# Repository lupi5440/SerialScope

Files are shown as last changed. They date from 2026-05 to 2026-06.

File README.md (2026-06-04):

# 🔬 SerialScope — Sistema de Análisis de Protocolos




**SerialScope** es un ecosistema de hardware y software diseñado para la visualización, análisis y emulación de protocolos de comunicación serial (**UART, I²C y SPI**). Esta introduce capacidades de **Maestro Activo**, permitiendo interactuar con sensores reales (como el MAX6675) y emular dispositivos complejos directamente desde una interfaz web .

---

## 🏗️ Arquitectura del Sistema (V3)

El sistema utiliza una arquitectura híbrida para garantizar que la visualización no afecte el rendimiento del bus físico.

```mermaid
graph TD
    subgraph Dashboard
        WEB[Interfaz Web - Vite/React]
    end

    subgraph Hardware_Cores
        VIS[ESP32 Visualizador]
        MST[ESP32 Maestro de Pruebas]
        SLV[ESP32 Esclavo de Pruebas]
    end

    WEB -- "WiFi (WebSockets)" --> VIS
    WEB -- "Bluetooth (BLE)" --> MST
    WEB -- "Bluetooth (BLE)" --> SLV

    MST -- "Bus Físico (I2C/SPI/UART)" --> VIS
    VIS -- "MISO/SDA/RX" --> WEB
    MST -- "UART" --> SLV
```

### 🛰️ Componentes Hardware
| Componente | Conectividad | Propósito |
|---|---|---|
| **Visualizador (Sniffer/Master)** | **WiFi** | Analizador lógico pasivo o **Maestro SPI/I2C** directo para leer sensores. |
| **Maestro (Emulador)** | **BLE** | Genera tráfico controlado, emula sensores (BMP180/TMP102) y controla periféricos (TFT). |
| **Esclavo (Receptor)** | **BLE** | Extremo final de la ráfaga UART para pruebas de integridad y bidireccionalidad. |

---

## 🚀 Capacidades 

### ⚡ Protocolo SPI (Serial Peripheral Interface)
- **Sniffing Pasivo:** Monitoreo en tiempo real de ráfagas MOSI/MISO sincronizadas con el reloj (SCK).
- **Maestro Activo:** Capacidad de generar el reloj (SCK) y CS para leer sensores (ej. MAX6675) y controlar periféricos (TFT).
- **Emulación de Sensor:** El visualizador puede actuar como Esclavo para responder a otros maestros con datos HEX personalizados.

### 🧩 Protocolo I²C (Inter-Integrated Circuit)
- **Auto-Sniffing:** Captura automática de direcciones y registros mediante interrupciones de hardware.
- **Maestro Activo:** Capacidad de lectura y escritura directa sobre dispositivos esclavos desde la interfaz web.
- **Emulación de Sensor:** Simulación de una memoria de registros (256 bytes) para pruebas de integración.

### 📡 Protocolo UART (Comunicación Serial)
- **Sniffing Pasivo:** Intercepción de mensajes entre dos dispositivos (Proxy transparente).
- **Maestro Activo:** Generación de mensajes seriales con baudrates configurables (9600 a 115200).
- **Emulación:** Respuesta automática controlada para validación de enlaces bidireccionales.

---

## 🛠️ Instalación y Uso

### Interfaz Web
La interfaz utiliza **Vite** para una experiencia rápida y un diseño basado en **Glassmorphism**.
```bash
cd WebInterface
npm install
npm run dev
```
Accede a `http://localhost:5173` para entrar al panel de control.

### Firmware (ESP32)
Es **CRÍTICO** utilizar el **ESP32 Arduino Core 3.0.0+** debido al uso de las APIs de PWM (`ledcAttach`). Puedes encontrar más información sobre este cambio [aquí](https://docs.espressif.com/projects/arduino-esp32/en/latest/api/ledc.html).

**Librerías Requeridas:**
- `Adafruit GFX Library` (v1.11.9)
- `Adafruit ST7735 and ST7789 Library` (v1.10.3)
- `MAX6675 library` (v1.1.2)
- [AsyncTCP (Fork de mathieucarbou)](https://github.com/mathieucarbou/AsyncTCP)
- [ESPAsyncWebServer (Fork de mathieucarbou)](https://github.com/mathieucarbou/ESPAsyncWebServer)

**Software de Desarrollo:**
- **Arduino IDE**: 2.3.2+ o VS Code + PlatformIO.
- **ESP32 Arduino Core**: 3.0.0 o superior.

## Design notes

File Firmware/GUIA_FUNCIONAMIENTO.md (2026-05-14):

# 📘 Auxiliar de Protocolos: I2C y SPI (Modos Activos y Esclavos)

Este documento detalla el procedimiento para interactuar con dispositivos en modo **Maestro (Activo)** y **Esclavo (Emulado)** usando el ecosistema SerialScope.

---

## 🌐 Protocolo I2C

### 1. Modo Maestro (Visualizador)

Se usa para interrogar a sensores reales o emulados.

#### TMP102 lectura

**Lectura de Temperatura (TMP102):**
- **Dirección:** `0x48` (ADD0 -> GND) o `0x49` (ADD0 -> VCC).
- **Registro:** `0x00` (Temperature Register).
- **Bytes a leer:** `2`.
- **Fórmula de Conversión:**
  1. Unir los dos bytes: `(Byte1 << 8 | Byte2)`.
  2. Desplazar 4 bits a la derecha: `Valor >> 4`.
  3. Multiplicar por la resolución: `Resultado * 0.0625 = °C`.
  *Ejemplo:* `17, D0` -> `0x17D0` -> `0x17D` (381) -> **23.81 °C**.

#### BMP180 lectura

**Lectura de Temperatura (BMP180):**
Este sensor requiere un proceso de **dos pasos** (Escritura + Lectura):

1. **PASO 1 (Pedir lectura)**: 
   - *Dirección:* `0x77` | *Registro:* `0xF4` | *Datos:* `2E`
   - Pulsa **ESCRIBIR**. Esto le dice al sensor que empiece a medir la temperatura.
2. **PASO 2 (Recoger dato)**:
   - Espera un momento (5-10ms).
   - *Dirección:* `0x77` | *Registro:* `0xF6` | *Bytes:* `2`
   - Pulsa **SOLICITAR**. Recibirás el dato crudo (UT), por ejemplo: `6E, 5A`.

**Fórmula de Conversión (Bosch):**
Una vez tienes el dato crudo (`UT`), la temperatura real (`T`) se calcula así:
1. `X1 = (UT - AC6) * AC5 / 2^15`
2. `X2 = (MC * 2^11) / (X1 + MD)`
3. `B5 = X1 + X2`
4. `T = (B5 + 8) / 2^4`
*(El resultado final se divide entre 10 para tener grados Celsius).*

**Lectura de Calibración (BMP180):**
- **Dirección:** `0x77` | **Registro:** `0xAA` | **Bytes:** `22`
- El sensor devuelve 11 valores (2 bytes cada uno) en este orden exacto:
  `AC1, AC2, AC3, AC4, AC5, AC6, B1, B2, MB, MC, MD`
- *Ejemplo:* Los primeros 2 bytes son `AC1`, los siguientes 2 son `AC2`, y así hasta llegar a los últimos 2 que son `MD`.

#### TMP102 escritura (Configuración alarma)

**Configuración de Alarma (TMP102):**
- **Registro:** `0x03` (T-High Register).
- **Bytes a escribir:** 2 bytes en Hex.
- **Lógica de cálculo:** `(Temperatura / 0.0625) << 4`.

| Temperatura deseada | Cálculo (Grados / 0.0625) | Valor Hex (12 bits) | Formato 16 bits (<< 4) | **Datos a poner en Web** |
|:---:|:---:|:---:|:---:|:---|
| **40 °C** | 640 | `0x280` | `0x2800` | **28, 00** |
| **20 °C** | 320 | `0x140` | `0x1400` | **14, 00** |
| **25.5 °C** | 408 | `0x198` | `0x1980` | **19, 80** |

**Pasos en la Interfaz del Visualizador:**
1. Dirección I2C: `0x48`.
2. Registro: `0x03`.
3. Datos (Hex): `28, 00` (para 40°C) o `14, 00` (para 20°C).
4. Botón: **ESCRIBIR**.

### 2. Modo Esclavo (Visualizador)
Se usa para que el Visualizador finja ser un sensor y responda al Maestro (ESP32 Pruebas).

1. **Conexión:** Une SDA(21), SCL(22) y GND de ambas placas.
2. **Visualizador (Esclavo):**
   - Elige `I2C Esclavo`.
   - Dirección: `0x48` | Registro: `0x00`.
   - Datos: `17, D0` (equivale a 23.94°C) o `28, 00` (equivale a 40.98°C)
   - Dale a **Aplicar al Hardware**.
3. **Maestro (Pruebas):**
   - Elige `I2C Maestro`.
   - Perfil: `TMP102` | Dirección: `0x48`.
   - Dale a **Sincronizar Maestro**.
4. **Resultado:** Deberías ver en la pantalla de Pruebas que el Maestro lee exactamente **23.94°C** o **40.98°C**. Si cambias los datos en el Visualizador, la temperatura cambiará en el Maestro.

---

## ⚡ Protocolo SPI

### 1. Modo Maestro (Visualizador)

**IMPORTANTE**: Se debe desconectar del paralelo el maestro del sensor , si se mantiene conectado el Visualizador se puede ver afectado y no funcionara correctamente.

**Operación:** El Visualizador genera el reloj (SCK) y selecciona al esclavo (CS).
**Transferencia:** Envías bytes por MOSI y recibes simultáneamente por MISO.

#### Configuración MAX6675

**Configuración**:
   - Selecciona **SPI (Maestro Activo)**.
   - **Modo**: Selecciona el modo del sensor (Modo 0 es el estándar para MAX6675).
   - **Frecuencia**: Selecciona la velocidad (ej: 1 MHz).
   - Haz clic en **Aplicar al Hardware**. El LED Azul del ESP32 parpadeará indicando la velocidad.
**Transferencia de Datos**:
   - En el cuadro "Datos a transferir", escribe los bytes en HEX.
   - **Para leer el Termopar**: Escribe `00 00`. 
     - *¿Por qué?* Porque el sensor entrega **16 bits** de datos. Cada `00` genera 8 pulsos de reloj. 2 bytes = 16 bits exactos.
     - *¿Puedo pedir más?* No. El sensor solo tiene 16 bits de memoria por lectura. Si pides más (ej: `00 00 00`), recibirás ceros después del segundo byte.
   - Haz clic en **Transferir**.

**Resultado y Conversión (MISO)**:
Al transferir, recibirás algo como `02, B0`.

**¿Cómo convertir `02 B0` a Grados Celsius?**
1. **Unir los bytes**: `0x02` y `0xB0` forman `0x02B0`.
2. **Eliminar bits de estado**: El sensor usa los últimos 3 bits para diagnóstico. Debes desplazar el valor 3 bits a la derecha:
   - En calculadora: `0x02B0 >> 3 = 86` (decimal).
3. **Multiplicar por resolución**: Cada unidad equivale a 0.25°C.
   - `86 * 0.25 = 21.5 °C`.

### 2. Modo Esclavo (Visualizador) - Emulación de Sensor

Este modo sirve para que el Visualizador finja ser un sensor y responda a otor maestro SPI.

#### Caso: Emular Termopar MAX6675

**Configuración en Visualizador (Esclavo)**:
   - Selecciona **SPI (Esclavo)**.
   - **Datos de Respuesta (MISO)**: Escribe los bytes que quieres que el Maestro reciba.
     - *Ejemplo*: Escribe `02 B0` (simula 43 °C) o `02 38` (simula 35.50 °C).
   - Haz clic en **Aplicar al Hardware**. El Visualizador ahora está "en espera".

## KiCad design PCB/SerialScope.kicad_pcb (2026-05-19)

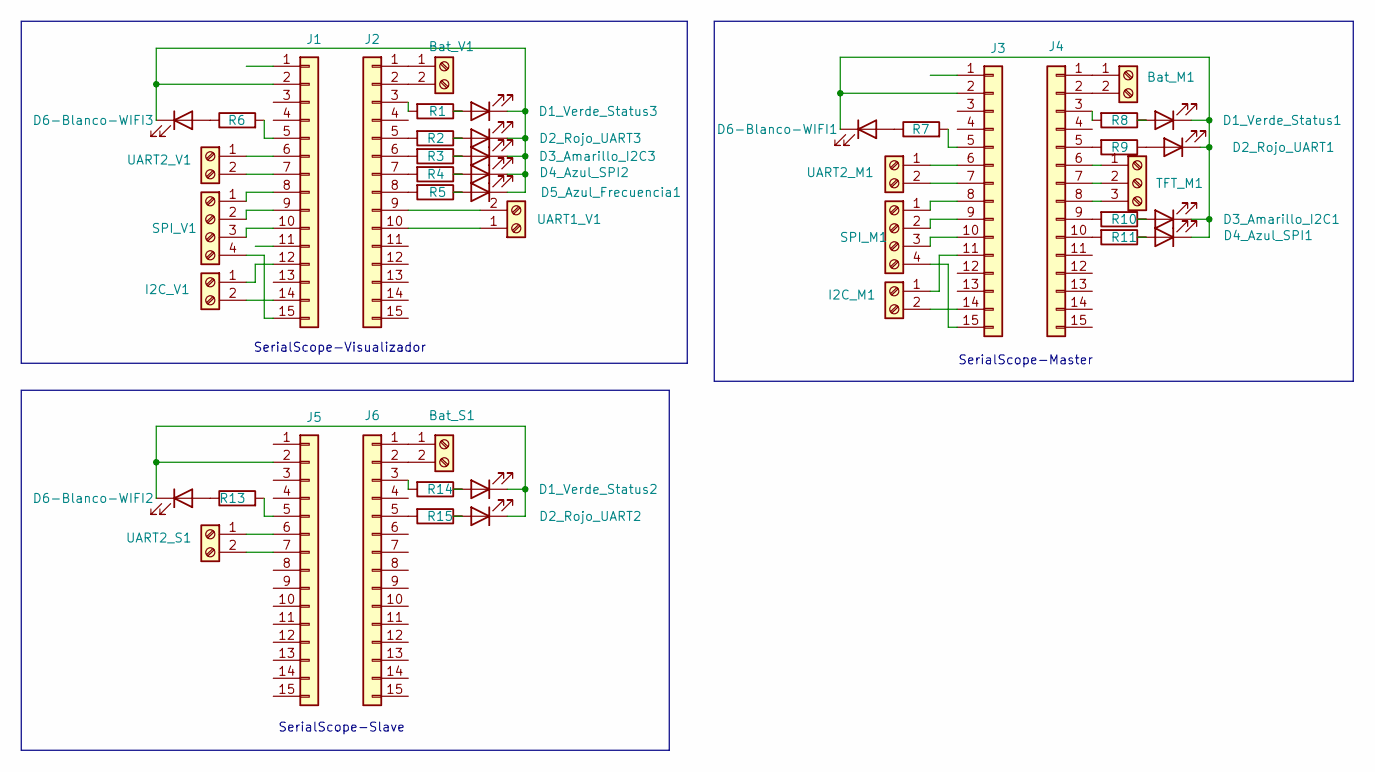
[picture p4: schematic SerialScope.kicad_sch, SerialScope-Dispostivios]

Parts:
Bat_M1: Screw_Terminal_01x02; TerminalBlock_MaiXu_MX126-5.0-02P_1x02_P5.00mm
Bat_S1: Screw_Terminal_01x02; TerminalBlock_MaiXu_MX126-5.0-02P_1x02_P5.00mm
Bat_V1: Screw_Terminal_01x02; TerminalBlock_MaiXu_MX126-5.0-02P_1x02_P5.00mm
D1_Verde_Status1, D1_Verde_Status2, D1_Verde_Status3, D2_Rojo_UART1, D2_Rojo_UART2, D2_Rojo_UART3, D3_Amarillo_I2C1, D3_Amarillo_I2C3, D4_Azul_SPI1, D4_Azul_SPI2, D5_Azul_Frecuencia1, D6-Blanco-WIFI1, D6-Blanco-WIFI2, D6-Blanco-WIFI3: LED; LED_D5.0mm
I2C_M1, I2C_V1: Screw_Terminal_01x02; TerminalBlock_MaiXu_MX126-5.0-02P_1x02_P5.00mm
J1, J2, J3, J4, J5, J6: Conn_01x15; PinSocket_1x15_P2.54mm_Vertical
R1, R2, R3, R4, R5, R6, R7, R8, R9, R10, R11, R13, R14, R15: 330; R_Axial_DIN0207_L6.3mm_D2.5mm_P10.16mm_Horizontal
SPI_M1: Screw_Terminal_01x04; TerminalBlock_MaiXu_MX126-5.0-04P_1x04_P5.00mm
SPI_V1: Screw_Terminal_01x04; TerminalBlock_MaiXu_MX126-5.0-04P_1x04_P5.00mm
TFT_M1: Screw_Terminal_01x03; TerminalBlock_MaiXu_MX126-5.0-03P_1x03_P5.00mm
UART1_V1, UART2_M1, UART2_S1, UART2_V1: Screw_Terminal_01x02; TerminalBlock_MaiXu_MX126-5.0-02P_1x02_P5.00mm

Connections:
unnamed: Bat_M1.1, J4.1
unnamed: Bat_M1.2, J4.2
unnamed: Bat_S1.1, J6.1
unnamed: Bat_S1.2, J6.2
unnamed: Bat_V1.1, J2.1
unnamed: Bat_V1.2, J2.2
unnamed: D1_Verde_Status1.2 (A), R8.1
unnamed: D1_Verde_Status1.1 (K), D2_Rojo_UART1.1 (K), D3_Amarillo_I2C1.1 (K), D4_Azul_SPI1.1 (K), D6-Blanco-WIFI1.1 (K), J3.2
unnamed: D1_Verde_Status2.2 (A), R14.1
unnamed: D1_Verde_Status2.1 (K), D2_Rojo_UART2.1 (K), D6-Blanco-WIFI2.1 (K), J5.2
unnamed: D1_Verde_Status3.2 (A), R1.1
unnamed: D1_Verde_Status3.1 (K), D2_Rojo_UART3.1 (K), D3_Amarillo_I2C3.1 (K), D4_Azul_SPI2.1 (K), D5_Azul_Frecuencia1.1 (K), D6-Blanco-WIFI3.1 (K), J1.2
unnamed: D2_Rojo_UART1.2 (A), R9.1
unnamed: D2_Rojo_UART2.2 (A), R15.1
unnamed: D2_Rojo_UART3.2 (A), R2.1
unnamed: D3_Amarillo_I2C1.2 (A), R10.1
unnamed: D3_Amarillo_I2C3.2 (A), R3.1
unnamed: D4_Azul_SPI1.2 (A), R11.1
unnamed: D4_Azul_SPI2.2 (A), R4.1
unnamed: D5_Azul_Frecuencia1.2 (A), R5.1
unnamed: D6-Blanco-WIFI1.2 (A), R7.1
unnamed: D6-Blanco-WIFI2.2 (A), R13.1
unnamed: D6-Blanco-WIFI3.2 (A), R6.1
unnamed: I2C_M1.1, J3.11
unnamed: I2C_M1.2, J3.14
unnamed: I2C_V1.1, J1.12
unnamed: I2C_V1.2, J1.14
unnamed: J1.5, R6.2
unnamed: J1.6, UART2_V1.1
unnamed: J1.7, UART2_V1.2
unnamed: J1.8, SPI_V1.1
unnamed: J1.9, SPI_V1.2
unnamed: J1.10, SPI_V1.3
unnamed: J1.15, SPI_V1.4
unnamed: J2.3, R1.2
unnamed: J2.5, R2.2
unnamed: J2.6, R3.2
unnamed: J2.7, R4.2
unnamed: J2.8, R5.2
unnamed: J2.9, UART1_V1.2
unnamed: J2.10, UART1_V1.1
unnamed: J3.5, R7.2
unnamed: J3.6, UART2_M1.1
unnamed: J3.7, UART2_M1.2
unnamed: J3.8, SPI_M1.1
unnamed: J3.9, SPI_M1.2
unnamed: J3.10, SPI_M1.3
unnamed: J3.15, SPI_M1.4
unnamed: J4.3, R8.2
unnamed: J4.5, R9.2
unnamed: J4.6, TFT_M1.1
unnamed: J4.7, TFT_M1.2
unnamed: J4.8, TFT_M1.3
unnamed: J4.9, R10.2
unnamed: J4.10, R11.2
unnamed: J5.5, R13.2
unnamed: J5.6, UART2_S1.1
unnamed: J5.7, UART2_S1.2
unnamed: J6.3, R14.2
unnamed: J6.5, R15.2

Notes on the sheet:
SerialScope-Slave
SerialScope-Visualizador
SerialScope-Master

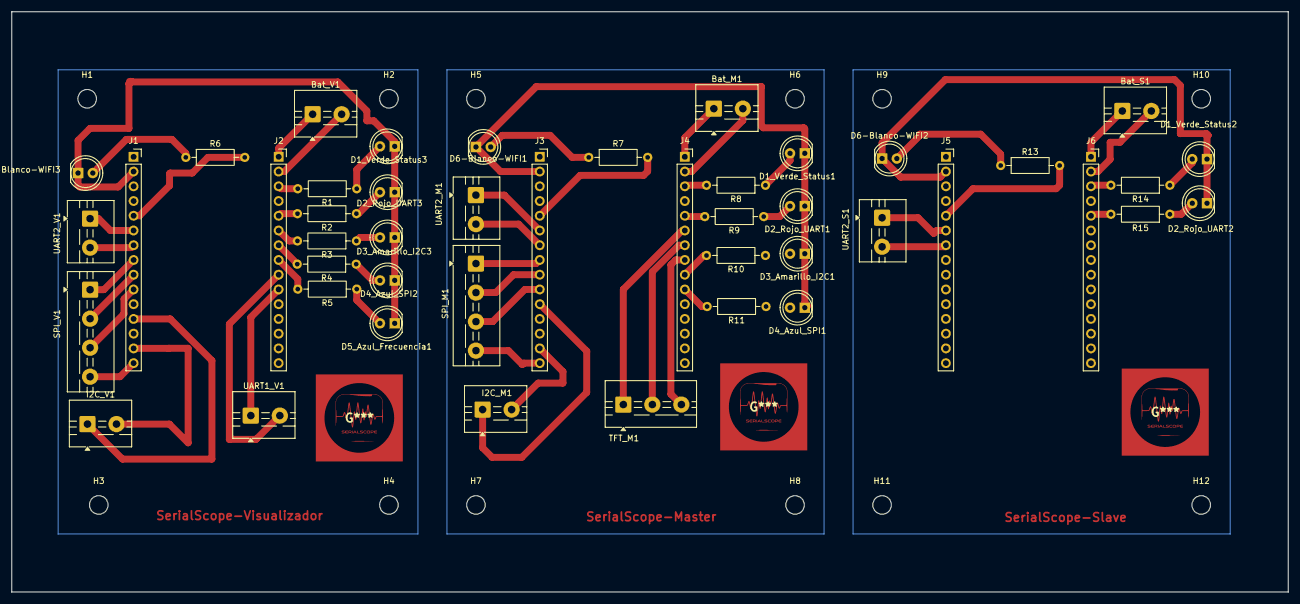
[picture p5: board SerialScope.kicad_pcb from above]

Board: 2 copper layers, 220.0 x 100.0 mm, 58 parts (0 on the bottom side), 60 nets.

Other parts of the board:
H1, H2, H3, H4, H5, H6, H7, H8, H9, H10, H11, H12: MountingHole_3.2mm_M3

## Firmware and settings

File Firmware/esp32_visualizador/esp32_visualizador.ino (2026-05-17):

/*
 * =====================================================================================
 *  PROYECTO : SerialScope — Visualizador (Sniffer / Proxy)
 *  ARCHIVO  : esp32_visualizador.ino
 * =====================================================================================
 *
 *  DESCRIPCIÓN:
 *    Firmware del ESP32 Visualizador. Captura tráfico de bus y lo retransmite a la interfaz web vía WebSocket sobre WiFi.
 *
 *  MODOS DE OPERACIÓN:
 *    - UART (Proxy)        : Todo el trafico recibido por el canal serial 1 lo reenvia al canal serial 2  y viceversa
 *    - I²C  (Sniffer)      : Recibe por interrupcion todo el trafico de I2C y lo muestra en la web
 *    - I²C  (Maestro)      : Se comporta como un maestro I2C y puede configurarse para pedir datos a un esclavo 
 *    - I²C  (Esclavo)      : Se comporta como un esclavo I2C y puede configurarse para recibir datos de un maestro 
 *    - SPI  (Sniffer)      : Recibe por interrupcion todo el trafico de SPI y lo muestra en la web
 *    - SPI  (Maestro)      : Se comporta como un maestro SPI y puede configurarse para pedir datos a un esclavo 
 *    - SPI  (Esclavo)      : Se comporta como un esclavo SPI y puede configurarse para recibir datos de un maestro 
 *
 *  PINOUT SEGURO:
 *    LEDs     → GPIO 13 (Verde-Status), 4 (Blanco-wifi), 14 (Rojo-UART), 27 (Amarillo-I2C), 26 (Azul-SPI), 25 (Frecuencia-SPI)  
 *    UART     → Serial1 rempapeado: RX:33, TX:32  |  Serial2: RX:17, TX:16
 *    I²C      → SCL:22, SDA:21 
 *    SPI      → SCK:18, MISO:19, MOSI:23, CS:5
 *
 *  RED WiFi:          "SerialScope_Visualizador"              Password: 12345
 *  WebSocket:         ws://192.168.4.1                        Puerto:80
 *
 * =====================================================================================
 */

#include <WiFi.h>
#include <AsyncTCP.h>
#include <ESPAsyncWebServer.h>
#include <Wire.h>
#include <SPI.h>
#include "soc/soc.h"           // Librería para control de registros
#include "soc/rtc_cntl_reg.h"  // Librería para control de Brownout (para que si hay poca corriente no se reinicie)

// Configuracion de WiFi
const char* ssid = "SerialScope_Visualizador";
const char* password = "12345678";  //Minimo debe tener 8 caracteres para contraseña
AsyncWebServer server(80);
AsyncWebSocket ws("/ws");

// Pines para LEDs indicadores 
#define LED_STATUS_VERDE   13  // Verde (Status)
#define LED_WIFI_BLANCO    4   // Blanco (WiFi)
#define LED_UART_ROJO      14  // Rojo (UART)
#define LED_I2C_AMARILLO   27  // Amarillo (I2C)
#define LED_SPI_AZUL       26  // Azul (SPI)
#define LED_SPI_FREC_AZUL  25  // AZUL Frecuencia (SPI)

// --- PINES DE HARDWARE ---
#define UART_LOCAL_RX_PIN  16 // Pin RX nativo
#define UART_LOCAL_TX_PIN  17 // Pin TX nativo
#define UART_PROXY_RX_PIN  33 // Pin RX remapeado
#define UART_PROXY_TX_PIN  32 // Pin TX remapeado
#define I2C_SDA_PIN        21 // Pin Datos I2C
#define I2C_SCL_PIN        22 // Pin Reloj I2C
#define SPI_SCK_PIN        18 // Reloj SPI
#define SPI_MISO_PIN       19 // Master In Slave Out
#define SPI_MOSI_PIN       23 // Master Out Slave In
#define SPI_CS_PIN         5  // Chip Select

// --- TIEMPOS Y PARÁMETROS DEL SISTEMA (Milisegundos) ---
#define WIFI_BLINK_MS          1000  // Parpadeo buscando WiFi
#define PROTOCOL_BLINK_MS      200   // Velocidad parpadeo protocolos
#define PROTOCOL_REST_MS       1500  // Pausa entre secuencias protocolos
#define FREQ_BLINK_MS          150   // Velocidad parpadeo LED Frecuencia
#define FREQ_REST_MS           1500  // Pausa parpadeo LED Frecuencia
#define PING_LED_MS            500   // Duración alerta PING

// Control de parpadeo de los LEDs de protocolo
uint8_t ledBlinkTarget = 0;              // uint8_t para ahorrar memoria
uint8_t ledBlinkCount = 0;
bool ledBlinkState = false;
bool ledResting = false;
unsigned long lastProtocolLedTime = 0;   // Temporizador para el parpadeo

// Control de parpadeo LED frecuencia SPI
uint8_t freqBlinkTarget = 0;            
uint8_t freqBlinkCount = 0;
bool freqBlinkState = false;
bool freqResting = false;
unsigned long lastFreqLedTime = 0;       // Temporizador para la frecuencia

// Control de parpadeo LED de estado y WiFi
bool blinkState = false;                 // Estado del parpadeo general (WiFi)
unsigned long lastBlinkTime = 0;         // Temporizador general (WiFi)
unsigned long whiteLedOffTime = 0; 
unsigned long greenLedTurnOffTime = 0;

// Temporizadores individuales
unsigned long redLedOffTime = 0;
unsigned long blueLedOffTime = 0; 
unsigned long lastFlushTime = 0;       

// Protocolo actual
String currentProtocol = "";

// Instancia para reservar pines SPI 
SPIClass SPI_Sensing(VSPI);

// Definicion de modos SPI y Roles para los protocolos SPI e I2C
uint8_t spi_modes[] = {SPI_MODE0, SPI_MODE1, SPI_MODE2, SPI_MODE3};
enum Role { ROLE_SNIFFER, ROLE_MASTER, ROLE_SLAVE };  

// Intervalo de tiempo en milisegundos para enviar los datos por WiFi y evitar saturación
const int FLUSH_INTERVAL = 20;  

//Variable para saber si el ESP está en alguna configuración.
volatile bool estaConfigurando = false;

// Funcion para enviar texto al WebSocket
void wsSend(String texto);

// Estructura para enviar por la cola
typedef struct {
    char cmd[512]; // Soporta comandos de hasta 127 caracteres
} MensajeComando;

// Identificador de la cola de FreeRTOS
QueueHandle_t colaComandos;


// Buffers para UART 
#define UART_BUF_SIZE 256
uint8_t rawBufferM2S[UART_BUF_SIZE];
int idxM2S = 0;

uint8_t rawBufferS2M[UART_BUF_SIZE];
int idxS2M = 0;

// Declaraciones de interrupciones (ISRs para i2c y spi)
void IRAM_ATTR onSCLRising();
void IRAM_ATTR onSDAChange();
void IRAM_ATTR onSCKChange(); 
void IRAM_ATTR onCSChange();  
void onI2CReceive(int numBytes);
void onI2CRequest();

volatile bool i2cSlaveMsgReady = false;
volatile bool i2cSlaveReqReady = false;
char i2cSlaveMsgBuffer[128];
char i2cSlaveReqBuffer[64];

Role i2cRole = ROLE_SNIFFER;
Role spiRole = ROLE_SNIFFER;

 // Parametros de configuracion I2C
long activeI2CSpeed = 100000;
int activeI2CAddr = 0x08;
int activeI2CReg = 0x00;

 // Varibles de snifing I2C
 #define I2C_BUFFER_SIZE 1024
 volatile uint8_t i2cRawBuffer[I2C_BUFFER_SIZE]; // Almacén circular para los bytes capturados
 volatile int i2cWriteIdx = 0;                   // Dónde escribe el sniffer (interrupciones)
 volatile int i2cReadIdx = 0;                    // Dónde lee el programa principal (loop)
 volatile unsigned long lastI2cTime = 0;         // Marca de tiempo para detectar fin de ráfaga
 volatile uint8_t i2cCurrentByte = 0;            // Byte que se está construyendo bit a bit
 volatile bool i2cStarted = false;               // Para pausar la captura de datos 
volatile int i2cBitCount = 0;                    // Contador de bits para identificar si es dirección o data

// Definiciones de lectura directa para I2C
#define READ_SCL_FAST ((REG_READ(GPIO_IN_REG) >> 22) & 1)
#define READ_SDA_FAST ((REG_READ(GPIO_IN_REG) >> 21) & 1)
 
// Variables de configuracion modo esclavo I2C y SPI
volatile uint8_t sensorMemory[256]; // 256 registros virtuales para emular el sensor
volatile uint8_t currentRegister = 0; // Apuntador al registro actual I2C

volatile bool spiSlaveMode = false;
volatile int spiSlaveBytePtr = 0;  //indice inicio registro byte
volatile int spiSlaveBitPtr = 0;   //indice bit
volatile uint8_t spiSlaveBuffer[256]; //buffer para SPI
volatile int spiSlaveBufferSize = 0;

// Parametros de configuracion SPI
long activeSPIFreq = 1000000;
int activeSPIMode = 0;

// Variables de estado SPI
 #define SPI_BUFFER_SIZE 512
 volatile uint8_t spiRawBuffer[SPI_BUFFER_SIZE];  //Buffer circular para SPI
 volatile int spiWriteIdx = 0;                    //Volatile para que la interrupción pueda acceder a ella
 volatile int spiReadIdx = 0;                     //Donde lee el programa principal
 volatile int spiBitCnt = 0;                      //Contador de bits para identificar si es dirección o data
 
// buffer temporal para recibir datos 
 volatile uint8_t spiByterx = 0;
 volatile uint8_t spiBytetx = 0;
 volatile unsigned long lastSpiTime = 0;

 // Lectura de registros para SPI (Acceso directo al hardware del ESP32)
 #define READ_MOSI_FAST ((REG_READ(GPIO_IN_REG) >> 23) & 1)
 #define READ_MISO_FAST ((REG_READ(GPIO_IN_REG) >> 19) & 1)
 #define READ_CS_FAST   ((REG_READ(GPIO_IN_REG) >> 5) & 1)
 #define READ_SCK_FAST  ((REG_READ(GPIO_IN_REG) >> 18) & 1)  //Saber si esta activo o no el SCK

// Setup principal
void setup() {
    
    // Inicialización de comunicación serial
    Serial.begin(115200);
    
    // DESACTIVAR BROWNOUT DETECTOR (Para evitar reinicios por caídas leves de voltaje)
    WRITE_PERI_REG(RTC_CNTL_BROWN_OUT_REG, 0); 
    
    delay(2000); // Esperar a que el voltaje se estabilice tras el encendido

    // Configuración de Pines Seriales 
    Serial1.begin(115200, SERIAL_8N1, UART_LOCAL_RX_PIN, UART_LOCAL_TX_PIN); 
    Serial2.begin(115200, SERIAL_8N1, UART_PROXY_RX_PIN, UART_PROXY_TX_PIN);
    
    // Cola de comando para evitar condicion de carrera entre loop y web socket
    colaComandos = xQueueCreate(10, sizeof(MensajeComando));
    if(colaComandos == NULL){
        Serial.println("[Error] >>> No se pudo crear la cola de comandos");
    }

    // Configuración de Pines SPI 
    SPI_Sensing.begin(18, 19, 23, 5);

    // Configurar interrupciones I2C 
    pinMode(I2C_SDA_PIN, INPUT_PULLUP);
    pinMode(I2C_SCL_PIN, INPUT_PULLUP);
    attachInterrupt(digitalPinToInterrupt(I2C_SCL_PIN), onSCLRising, RISING);
    attachInterrupt(digitalPinToInterrupt(I2C_SDA_PIN), onSDAChange, CHANGE);

    // Configuración de pines para LEDs
    pinMode(LED_UART_ROJO, OUTPUT);
    pinMode(LED_SPI_AZUL, OUTPUT);
    pinMode(LED_I2C_AMARILLO, OUTPUT);
    pinMode(LED_WIFI_BLANCO, OUTPUT);
    pinMode(LED_STATUS_VERDE, OUTPUT);
    pinMode(LED_SPI_FREC_AZUL, OUTPUT);
    
    // Estado inicial de LEDs 
    digitalWrite(LED_WIFI_BLANCO, LOW);
    digitalWrite(LED_STATUS_VERDE, LOW);
    digitalWrite(LED_SPI_FREC_AZUL, LOW);
    digitalWrite(LED_UART_ROJO, LOW);
    digitalWrite(LED_SPI_AZUL, LOW);
    digitalWrite(LED_I2C_AMARILLO, LOW);

    //btener el mejor canal de forma dinámica
    int canalOptimo = obtenerMejorCanalWiFi();
    
    // Configura el punto de acceso Wi-Fi
    WiFi.mode(WIFI_AP); 
    WiFi.softAP(ssid, password, canalOptimo, 0, 4);
    digitalWrite(LED_WIFI_BLANCO, HIGH);
    
    // Inicia el servidor web para manejar la comunicación con la interfaz web
    ws.onEvent(onEvent);
    server.addHandler(&ws);
    server.begin();

    Serial.println("[Sistema] >>> Visualizador SerialScope WiFi Online.");
    
}

// Main loop
void loop() {

    // Limpieza de clientes WebSocket desconectados
    ws.cleanupClients();

    // Procesar comandos desde la cola de comandos
    MensajeComando comandoRecibido;
    if (xQueueReceive(colaComandos, &comandoRecibido, 0) == pdTRUE) {
        String cmd = String(comandoRecibido.cmd);
        ejecutarComando(cmd);
    }
    
    if (estaConfigurando) return;

    manejarLEDs();
    
    // Lógica de lectura para UART como proxy transparente
    if (currentProtocol == "UART") {
        int readLimit = 0; // Freno de seguridad
        
        while (Serial1.available() && idxM2S < UART_BUF_SIZE && readLimit < 64) {
            uint8_t c = Serial1.read();
            Serial2.write(c); 
            rawBufferM2S[idxM2S++] = c;
            readLimit++;
        }

        readLimit = 0;
        while (Serial2.available() && idxS2M < UART_BUF_SIZE && readLimit < 64) {
            uint8_t c = Serial2.read();
            Serial1.write(c); 
            rawBufferS2M[idxS2M++] = c;
            readLimit++;
        }
    }

    // Empaquetado y envio por WiFi para SPI, I2C y UART
    if (millis() - lastFlushTime > FLUSH_INTERVAL) {
        
        if (currentProtocol == "SPI") {
            if (spiReadIdx != spiWriteIdx) {
                lastSpiTime = millis();  
                
                // Buffer estático para SPI
                char sendBuf[512]; 
                int len = snprintf(sendBuf, sizeof(sendBuf), "SPI_RECV_BUF:");
                int maxBytes = 0;
                
                // Escribimos directamente en el buffer estático
                while (spiReadIdx != spiWriteIdx && maxBytes < 150 && len < 490) { 
                    len += snprintf(sendBuf + len, sizeof(sendBuf) - len, "%02X,", spiRawBuffer[spiReadIdx]); 
                    spiReadIdx = (spiReadIdx + 1) % SPI_BUFFER_SIZE;
                    maxBytes++;
                }
                wsSend(String(sendBuf));
            }
        }
        
        else if (currentProtocol == "I2C") {
            if (i2cReadIdx != i2cWriteIdx && (millis() - lastI2cTime > 10)) {
                lastI2cTime = millis();  
                
                char sendBuf[512]; 
                int len = snprintf(sendBuf, sizeof(sendBuf), "I2C_RECV_BUF:");
                int maxBytes = 0;
                
                while (i2cReadIdx != i2cWriteIdx && maxBytes < 150 && len < 490) { 
                    len += snprintf(sendBuf + len, sizeof(sendBuf) - len, "%02X,", i2cRawBuffer[i2cReadIdx]);
                    i2cReadIdx = (i2cReadIdx + 1) % I2C_BUFFER_SIZE;
                    maxBytes++;
                }
                wsSend(String(sendBuf));
            }
        }
        
        else if (currentProtocol == "UART") {
            if (idxM2S > 0) {
                char sendBuf[512];
                int len = snprintf(sendBuf, sizeof(sendBuf), "UART_RECV_BUF:M2S:");
                for (int i = 0; i < idxM2S && len < 490; i++) {
                    len += snprintf(sendBuf + len, sizeof(sendBuf) - len, "%02X,", rawBufferM2S[i]); 
                }
                wsSend(String(sendBuf));
                idxM2S = 0; 
            }

            if (idxS2M > 0) {
                char sendBuf[512];
                int len = snprintf(sendBuf, sizeof(sendBuf), "UART_RECV_BUF:S2M:");
                for (int i = 0; i < idxS2M && len < 490; i++) {
                    len += snprintf(sendBuf + len, sizeof(sendBuf) - len, "%02X,", rawBufferS2M[i]);
                }
                wsSend(String(sendBuf));
                idxS2M = 0; 
            }
        }
        
        lastFlushTime = millis(); 
    }

    // Revisamos las banderas del Esclavo I2C para enviar mensaje
    if (i2cSlaveMsgReady) {
        wsSend(String((char*)i2cSlaveMsgBuffer));
        i2cSlaveMsgReady = false;
    }
    if (i2cSlaveReqReady) {
        wsSend(String((char*)i2cSlaveReqBuffer));
        i2cSlaveReqReady = false;
    }
}

// Actualizar LEDs según el protocolo
void actualizarLedsProtocolo(String proto, int blinks) {
    
    // RE-INICIALIZACIÓN: Asegurar que los pines de los LEDs sean SALIDAS.
    // Algunos periféricos (como UART o I2C) pueden resetear el modo de los pines al iniciarse.
    pinMode(LED_UART_ROJO, OUTPUT);
    pinMode(LED_I2C_AMARILLO, OUTPUT);
    pinMode(LED_SPI_AZUL, OUTPUT);
    pinMode(LED_WIFI_BLANCO, OUTPUT);
    pinMode(LED_STATUS_VERDE, OUTPUT);
    pinMode(LED_SPI_FREC_AZUL, OUTPUT);

    // Limpiar el estado de los LEDs de protocolo
    digitalWrite(LED_UART_ROJO, LOW);
    digitalWrite(LED_I2C_AMARILLO, LOW);
    digitalWrite(LED_SPI_AZUL, LOW);
    digitalWrite(LED_STATUS_VERDE, LOW);
    digitalWrite(LED_SPI_FREC_AZUL, LOW);
    
    currentProtocol = proto;
    ledBlinkTarget = blinks;
    ledBlinkCount = 0;
    ledBlinkState = false;
    ledResting = false;
    lastProtocolLedTime = millis();

    // Determinar qué LED prender según el protocolo 
    if (blinks == 0) {
        // Modo Sniffer (Fijo)
        if (proto == "I2C") digitalWrite(LED_I2C_AMARILLO, HIGH); 
        else if (proto == "SPI") digitalWrite(LED_SPI_AZUL, HIGH);   
        else if (proto == "UART") digitalWrite(LED_UART_ROJO, HIGH);
    } 
}

// Enviar texto al WebSocket (protege contra saturación)
void wsSend(String texto) {
    if (ws.count() > 0) {
        ws.textAll(texto);
    }
}

void limpiarTodosLosModos() {
    
    // Detener los 3 protocolos 
    stopSniffingI2C();
    detachInterrupt(digitalPinToInterrupt(SPI_SCK_PIN));
    detachInterrupt(digitalPinToInterrupt(SPI_CS_PIN));
    SPI_Sensing.end();
    Serial1.end();
    Serial2.end();
    
    // Limpiar variables de estado
    spiSlaveMode = false;
    i2cStarted = false;
    spiBitCnt = 0;
    i2cBitCount = 0;
    
    // Limpiar el estado de los LEDs de protocolo
    digitalWrite(LED_UART_ROJO, LOW);
    digitalWrite(LED_I2C_AMARILLO, LOW);
    digitalWrite(LED_SPI_AZUL, LOW);
    digitalWrite(LED_STATUS_VERDE, LOW);
    digitalWrite(LED_SPI_FREC_AZUL, LOW);
    
    // Apagar parpadeo de frecuencia del SPI
    freqBlinkTarget = 0;
}

// Función auxiliar para extraer parámetros de un comando (Formato: CMD:P1:P2:P3)
String getParam(String data, int index) {
    int found = 0;
    int strIndex[] = {0, -1};
    int maxIndex = data.length() - 1;

    for (int i = 0; i <= maxIndex && found <= index; i++) {
        if (data.charAt(i) == ':' || i == maxIndex) {
            found++;
            strIndex[0] = strIndex[1] + 1;
            strIndex[1] = (i == maxIndex) ? i + 1 : i;
        }
    }
    return found > index ? data.substring(strIndex[0], strIndex[1]) : "";
}

// Convertir paquete recibido por WS a comando de texto
void onEvent(AsyncWebSocket *server, AsyncWebSocketClient *client, AwsEventType type, void *arg, uint8_t *data, size_t len) {
    if (type == WS_EVT_CONNECT) {
        Serial.printf("[WiFi] >>> Cliente conectado a WebSockets (ID: %u)\n", client->id());
        client->text("[Sistema] >>> Conectado al Visualizador SerialScope");
        digitalWrite(LED_WIFI_BLANCO, HIGH); // Al conectar: encender LED blanco y mantenerlo fijo
    } else if (type == WS_EVT_DISCONNECT) {
        Serial.printf(">> [WiFi] Cliente desconectado (ID: %u)\n", client->id());
        actualizarLedsProtocolo("", 0); // Apagar todo cuando se vaya el cliente
    } else if (type == WS_EVT_DATA) {
        AwsFrameInfo *info = (AwsFrameInfo*)arg;
        if (info->final && info->index == 0 && info->len == len && info->opcode == WS_TEXT) {
    
            //Recibir el string temporalmente
            String msg = "";
            msg.reserve(len + 1); // Reserva de memoria para evitar fragmentación
            for(size_t i=0; i<len; i++) {
                msg += (char)data[i];
            }
            msg.trim(); 
            
            //Empaquetarlo en la cola
            MensajeComando nuevoComando;
            strncpy(nuevoComando.cmd, msg.c_str(), sizeof(nuevoComando.cmd) - 1);
            nuevoComando.cmd[sizeof(nuevoComando.cmd) - 1] = '\0'; // Asegurar fin de cadena
            
            //Empujar a la cola (sin bloquear el hilo asíncrono)
            if (colaComandos != NULL) {
                xQueueSend(colaComandos, &nuevoComando, (TickType_t)0);
            }
        }
    }
}
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

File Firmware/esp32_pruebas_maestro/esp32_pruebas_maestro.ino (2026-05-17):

/*
 * =====================================================================================
 *  PROYECTO : SerialScope — Módulo de Pruebas (Master)
 *  ARCHIVO  : esp32_pruebas_maestro.ino
 * =====================================================================================
 *
 *  DESCRIPCIÓN:
 *    Este es el "Cerebro" del banco de pruebas (Master). Su función es generar
 *    tráfico real y controlado en los buses UART, I2C y SPI para su análisis.
 *
 *  CARACTERÍSTICAS TÉCNICAS:
 *    - BLE UART: Control inalámbrico mediante interfaz Bluetooth.
 *    - UART : Generador de mensajes seriales a baudios variables.
 *    - I2C : Lectura e interpretacion de sensores  (BMP180 / TMP102).
 *    - SPI : Control de pantallas TFT (ST7735) y lectura de termopares tipo k (MAX6675).
 *
 *  CONEXIÓN DE PROTOCOLOS SUGERIDA:
 *    - UART : RX:16, TX:17
 *    - I2C : SDA:21, SCL:22
 *    - SPI : SCK:18, MISO:19, MOSI:23, CS:5 (MAX6675)
 *    - TFT Aux    : A0: 25 , RST:26, LED:27, 
 *    - La TFT tiene en el chip SDA pero en realidad es el MOSI     
*
 *  INDICADORES DE MODO SUGERIDO :
 *    - Verde (Status)  : GPIO 13
 *    - Blanco (BLE)    : GPIO 4
 *    - Rojo (UART)     : GPIO 14
 *    - Amarillo (I2C)  : GPIO 33
 *    - Azul (SPI)      : GPIO 32
 *=====================================================================================*/

#include <BLEDevice.h>
#include <BLEServer.h>
#include <BLEUtils.h>
#include <BLE2902.h>
#include <Wire.h>
#include <SPI.h>
#include "max6675.h"
#include <Adafruit_GFX.h>    
#include <Adafruit_ST7735.h> 

// --- BUS SPI ESTÁNDAR (Compartido) ---
#define SPI_SCK   18
#define SPI_MISO  19
#define SPI_MOSI  23
#define SPI_CS 5 

// --- PINES AUXILIARES PANTALLA ---
#define TFT_RST   26  // Reset (Reinicio físico de la pantalla)
#define TFT_DC    25  // Data/Command (Selector de Datos o Comandos)
#define TFT_LED   27  // Backlight (Control de Brillo/Luz de fondo)

// Objetos de Hardware (SPI)
MAX6675 thermocouple(SPI_SCK, SPI_CS, SPI_MISO);
Adafruit_ST7735 tft = Adafruit_ST7735(SPI_CS, TFT_DC, TFT_RST);
String spiProfile = "";

// UUIDs BLE UART Service
#define SERVICE_UUID           "6e400001-b5a3-f393-e0a9-e50e24dcca9e"
#define CHARACTERISTIC_UUID_RX "6e400002-b5a3-f393-e0a9-e50e24dcca9e"
#define CHARACTERISTIC_UUID_TX "6e400003-b5a3-f393-e0a9-e50e24dcca9e"

BLEServer *pServer = NULL;
BLECharacteristic *pTxCharacteristic = NULL;
bool deviceConnected = false;
bool oldDeviceConnected = false;

// Tiempos y parametros del sistema
#define BLE_BLINK_INTERVAL_MS      500   // Parpadeo cuando busca conexión BLE
#define PING_LED_DURATION_MS       500   // Tiempo del LED verde con PING
#define PROTOCOL_BLINK_INTERVAL_MS 200   // Velocidad de parpadeo de LEDs de protocolo
#define PROTOCOL_BLINK_REST_MS     1500  // Pausa entre secuencias de parpadeo
#define SENSOR_POLL_INTERVAL_MS    1000  // Cada cuánto hace "spam" de lectura a los sensores
#define BLE_CHUNK_SIZE             20    // Tamaño máximo del paquete de envío Bluetooth
#define BLE_MTU_SIZE               512   // Tamaño máximo de negociación Bluetooth
#define BLE_SEND_DELAY_MS          3    // Pausa entre envío de fragmentos BLE
#define UART_MAX_RX_BUFFER         256   // Límite de seguridad para lectura de UART

// Parametros de la pantalla TFT PWM
#define TFT_PWM_FREQ               5000  // Frecuencia PWM para la pantalla
#define TFT_PWM_RES                8     // Resolución PWM (8 bits = 0 a 255)
#define TFT_PWM_MAX                255   // Brillo máximo

// Estados de los modos del master
enum Modo { IDLE, UART_EMU, I2C_EMU, SPI_EMU };
Modo modoActual = IDLE;
unsigned long ultimaTarea = 0;
unsigned long contadorUART = 0;
bool emulacionActiva = false;
String comandoPendiente = ""; // Cola para procesar comandos BLE 

// --- PINES DE CONTROL Y HARDWARE ---
#define LED_STATUS_VERDE  13  // Verde (Alerta)
#define LED_BLE_BLANCO    4   // Blanco (BLE)
#define LED_UART_ROJO     14  // Rojo (UART)
#define LED_I2C_AMARILLO  33  // Amarillo (I2C)
#define LED_SPI_AZUL      32  // Azul (SPI)

#define UART_RX_PIN       16  // Pin recepción UART pruebas
#define UART_TX_PIN       17  // Pin transmisión UART pruebas
#define I2C_SDA_PIN       21  // Pin SDA para bus I2C
#define I2C_SCL_PIN       22  // Pin SCL para bus I2C

// Variables para el parpadeo de los LEDs
int ledBlinkTarget = 0;
int ledBlinkCount = 0;
bool ledBlinkState = false;
unsigned long lastProtocolLedTime = 0;
bool ledResting = false;
unsigned long greenLedTurnOffTime = 0;
unsigned long lastBlinkTime = 0;
bool blinkState = false;

// Parámetros Dinámicos I2C
String i2cProfile = "";
int i2cAddress = 0x77; // Default BMP180

// Prototipos de funciones
void ejecutarComando(String comando);
void bleSend(String texto);
void actualizarLeds(Modo m, int blinks);

// Callbacks BLE UART
class MyServerCallbacks: public BLEServerCallbacks {

    // Callback cuando el dispositivo se conecta
    void onConnect(BLEServer* pServer) { 
        deviceConnected = true; 
        Serial.println("Bluetooth Conectado"); 
    }

    // Callback cuando el dispositivo se desconecta
    void onDisconnect(BLEServer* pServer) { 
        deviceConnected = false; 
        digitalWrite(LED_BLE_BLANCO, LOW); 
        Serial.println("Bluetooth Desconectado"); 
        modoActual = IDLE;
        actualizarLeds(IDLE, 0);
    }
};

// Implementación de Callbacks para obtener comando recibido por ble de la interfaz
class MyCallbacks: public BLECharacteristicCallbacks {

    void onWrite(BLECharacteristic *pCharacteristic) {
        String rxValue = String(pCharacteristic->getValue().c_str());
        if (rxValue.length() > 0) {
            rxValue.trim();
            comandoPendiente = rxValue;
        }
    }
};

// Función para actualizar los LEDs
void actualizarLeds(Modo m, int blinks) {
    digitalWrite(LED_UART_ROJO, LOW);
    digitalWrite(LED_SPI_AZUL, LOW);
    digitalWrite(LED_I2C_AMARILLO, LOW);
    digitalWrite(LED_STATUS_VERDE, LOW); // Limpiar alertas al cambiar de modo
    modoActual = m;
    ledBlinkTarget = blinks;
    ledBlinkCount = 0;
    ledBlinkState = false;
    ledResting = false;
    lastProtocolLedTime = millis();
}
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

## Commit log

2026-05-07 archivo para despliege en githubpages
2026-05-07 Actualizacion porque no encontraba el package-lock.json
2026-05-07 Cambio de base en vite para que al subir si encuentre bien los enlaces a las paginas
2026-05-07 correcion al script de header
2026-05-10 Cambio de pines para facilitar conexion y mejorar velocidad
2026-05-11 Mejoras de salud y interfaz mas amigable
2026-05-12 Modificaciones pwa , colores interfaz actualizada, funcionamiento de los puertos
2026-05-12 Organizacion del codigo visualizador y cambio de variable de comando por una cola xQue para que no haya condicion de carrera entre el hilo 1 (wifi) y el hilo 2 (loop)
2026-05-12 Cambio de string de buffer de UART a arreglos fijos , para evitar que se creen string temporales y sobrecargen la ram
    [esp32_visualizador.ino]
2026-05-12 Solucion a problema de perdida de paquetes por ISP , y alerta cuando es necesario descartar datos de cola de paquetes a enviar a ws por diferentcia de de vleocidad entre sniffing y posibilidad que en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
    [esp32_visualizador.ino]
2026-05-12 Recerva de memoria para i2c y spi en snifing para evitar que llege muy rapido y llene directamente la ram por la cache que teniamos
2026-05-12 Anteriormente en el loop principal aunque no estaba seleccionado el protocolo hacea sniffing de los 3 i2c,spi,uart, sin embargo como en configuracion haciamos que solo se enviaran cuando el protocolo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
2026-05-12 borrado de parseo de parametros mal echo que teniamos en js entre diversas versiones de la interfaz
2026-05-13 Implementacion de I2C y SPi en dos formas , modo maestro y modo esclavo simulando ser un sensor , actualmetne esta la interfaz y logica en el visualizador , pero no se han echo pruebas
2026-05-13 Limpieza jscript para pruebas
2026-05-14 Quitar modo 1mhz en i2c y correccion de comportamiento de led de status cuando habia un error
    [esp32_pruebas_maestro.ino, esp32_pruebas_slave.ino, esp32_visualizador.ino]
2026-05-14 Agregar heartbeat a conexion wifi y ble , correccion problema spi , que cambio enter dispositivos , la libreria de uno bloqueaba a la de otro entonces solo funciona el primero que configurara, prueba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
    [esp32_pruebas_maestro.ino, esp32_visualizador.ino]
2026-05-14 Funcionamiento de todos los modos de los 3 protocolos , falta depurar hacer bien comentarios y organizar pero parece que es la ultima version en cuanto funcionalidad
2026-05-15 Correcciones para calidad de codigo , y mejorar en strings a printf para evitar saturacion de ram , asi mismo normalizacion de valores hardcodeados a su variables para futuro modificaciones
2026-05-15 Carpeta de firmware completa y funcional para documentar
2026-05-15 Actualizacion del readme con la nueva version
2026-05-16 Subida de archivos para PCB
    [SerialScope.kicad_pcb, SerialScope.kicad_sch]
2026-05-17 Correccion a manejo de strings , a paso a estandar de arreglos para arduino
    Implementacion de canal dinamico para wifi para menor ruido
    Ping ahora muestra la latencia en la comunicacion
    Por cuestiones de pegado y borrado la funcion de spi slave y master estaban duplicadas , se quitaron y pusieron bien ya que las dos hacian cosas a mitades
    [esp32_pruebas_maestro.ino, esp32_pruebas_slave.ino, esp32_visualizador.ino]
2026-05-19 Modificacion pcb , 2 mm extras de separacion entre las hileras de pines para esp32
    [SerialScope.kicad_pcb]
2026-05-19 Actualizacion medidas , correcciones de medidas
    [SerialScope.kicad_pcb]
2026-05-21 ACTUALIZACION SPI CON LEYENDA SPI
2026-05-21 CORREXION DE LEYENDAS EN EL SPI
2026-05-22 Correcion a titulos para quitar lo del rs232
2026-05-22 correccion de videos del index
